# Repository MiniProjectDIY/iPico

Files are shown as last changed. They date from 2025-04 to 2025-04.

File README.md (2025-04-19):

# iPico
RP2350 based UF2 hardware security key

## Hardware

iPico use the same IO as official raspberry pi Pico2 board, just replaced physical push button with capacitive touch button on pcb and change usb connector from female to male.

## Firmware
Use  [pico-fido](https://github.com/polhenarejos/pico-fido/releases) firmware for pico 2 board will do.

## Enclosure

3d printed case using file from 3D folder,using M1.4* 2 heat inserts and M1.4*5 counter sink screws.





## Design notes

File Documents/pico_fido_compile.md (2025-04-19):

# install sdk
```
git clone -b master https://github.com/raspberrypi/pico-sdk.git
cd pico-sdk
 git submodule update --init  --recursive
```
# install toolchain
`sudo apt install cmake gcc-arm-none-eabi build-essential   `
# install pico-fido source
```
git clone https://github.com/polhenarejos/pico-fido.git -b development
cd pico-fido
git submodule update --init  --recursive
mkdir build
cd build
```
# export PICO_SDK_PATH
`export PICO_SDK_PATH=/home/lifetyper/Code/pico-sdk`
# build using yubikey 5 NFC pid
```
cmake .. -DPICO_BOARD=pico2  -DUSB_VID=0x1050 -DUSB_PID=0x0407 -DENABLE_EDDSA=1
make
```

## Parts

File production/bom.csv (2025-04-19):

Designator | Footprint | Quantity | Value | LCSC Part #
C1 | 0402 | 1 | C_0402_4.7uF_6.3V_X5R
C11, C12, C14, C15, C18, C19, C6, C7 | 0402 | 8 | C_0402_100nF_10V_X7R
C13, C16 | 0402 | 2 | C_0402_15pF_50V_C0G
C2, C5 | 0402 | 2 | C_0402_10uF_10V_X5R
C20, C21, C22, C8 | 0402 | 4 | C_0402_4.7uF_10V_X5R
C3 | 0402 | 1 | C_0402_1uF_10V_X5R
C4 | 0402 | 1 | C_0402_1pF_50V_C0G
D1, D2 | 0402 | 2 | TPESD0402G05V
D3 | 0402 | 1 | NCD0402B1
F1 | 0402 | 1 | BSMD0402L-020
H1, H2, H3, H4 | MountingHole-M1.4 | 4 | MountingHole_Pad
J1 | GT-USB-8016A | 1 | GT-USB-8016A
JP1 | SolderJumper-2_P1.3mm_Open_Pad1.0x1.5mm | 1 | Jumper_2_Open
L1 | LT_L0806 | 1 | AOTA-B201610S3R3-101-T
R1 | 0402 | 1 | R_0402_5.1K_5%
R10 | 0402 | 1 | R_0402_33_5%
R2, R3, R4 | 0402 | 3 | R_0402_27_5%
R5, R6 | 0402 | 2 | R_0402_1K_5%
R7 | 0402 | 1 | R_0402_470_5%
U1 | USON8-2x3mm-EP0.2x1.6mm | 1 | ZD25WQ32CEIGR
U2 | RP2350A_QFN-60_EP_7.75x7.75_Pitch0.4mm | 1 | RP2350A-QFN60
U4 | SOT-23-6 | 1 | TTP223_SOT23-6
U5 | SOT-23 | 1 | 662K
Y1 | Crystal_SMD_2520-4Pin_2.5x2.0mm | 1 | ABM8-272-T3

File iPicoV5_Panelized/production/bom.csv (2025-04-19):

Designator | Footprint | Quantity | Value | LCSC Part #
_2, |  | 2
C1_5, C1_4, C1_3, C1_2, C1, C2_5, C2_4, C2_3, C2_2, C2, C20_5, C20_4, C20_3, C20_2, C20, C21_5, C21_4, C21_3, C21_2, C21, C22_5, C22_4, C22_3, C22_2, C22, C5_5, C5_4, C5_3, C5_2, C5, C8_5, C8_4, C8_3, C8_2, C8 | 0402 | 35 | C_0402_4.7uF_10V_X5R
C11_5, C11_4, C11_3, C11_2, C11, C12_5, C12_4, C12_3, C12_2, C12, C14_5, C14_4, C14_3, C14_2, C14, C15_5, C15_4, C15_3, C15_2, C15, C18_5, C18_4, C18_3, C18_2, C18, C19_5, C19_4, C19_3, C19_2, C19, C6_5, C6_4, C6_3, C6_2, C6, C7_5, C7_4, C7_3, C7_2, C7 | 0402 | 40 | C_0402_100nF_10V_X7R
C13_5, C13_4, C13_3, C13_2, C13, C16_5, C16_4, C16_3, C16_2, C16 | 0402 | 10 | C_0402_15pF_50V_C0G
C3_5, C3_4, C3_3, C3_2, C3 | 0402 | 5 | C_0402_1uF_10V_X5R
C4_5, C4_4, C4_3, C4_2, C4 | 0402 | 5 | C_0402_1pF_50V_C0G
D1_5, D1_4, D1_3, D1_2, D1, D2_5, D2_4, D2_3, D2_2, D2 | 0402 | 10 | TPESD0402G05V
D3_5, D3_4, D3_3, D3_2, D3 | 0603 | 5 | NCD0603B1
F1_5, F1_4, F1_3, F1_2, F1 | 0402 | 5 | BSMD0402L-020
J1_5, J1_4, J1_3, J1_2, J1 | GT-USB-8016A | 5 | GT-USB-8016A
L1_5, L1_4, L1_3, L1_2, L1 | LT_L0806 | 5 | AOTA-B201610S3R3-101-T
R1_5, R1_4, R1_3, R1_2, R1 | 0402 | 5 | R_0402_5.1K_5%
R10_5, R10_4, R10_3, R10_2, R10 | 0402 | 5 | R_0402_33_5%
R2_5, R2_4, R2_3, R2_2, R2, R3_5, R3_4, R3_3, R3_2, R3, R4_5, R4_4, R4_3, R4_2, R4 | 0402 | 15 | R_0402_27_5%
R5_5, R5_4, R5_3, R5_2, R5, R6_5, R6_4, R6_3, R6_2, R6 | 0402 | 10 | R_0402_1K_5%
R7_5, R7_4, R7_3, R7_2, R7 | 0402 | 5 | R_0402_470_5%
U1_5, U1_4, U1_3, U1_2, U1 | USON8-2x3mm-EP0.2x1.6mm | 5 | ZD25WQ32CEIGR
U2_5, U2_4, U2_3, U2_2, U2 | RP2350A_QFN-60_EP_7.75x7.75_Pitch0.4mm | 5 | RP2350A-QFN60
U4_5, U4_4, U4_3, U4_2, U4 | SOT-23-6 | 5 | TTP223_SOT23-6
U5_5, U5_4, U5_3, U5_2, U5 | SOT-23 | 5 | 662K
Y1_5, Y1_4, Y1_3, Y1_2, Y1 | Crystal_SMD_2520-4Pin_2.5x2.0mm | 5 | ABM8-272-T3

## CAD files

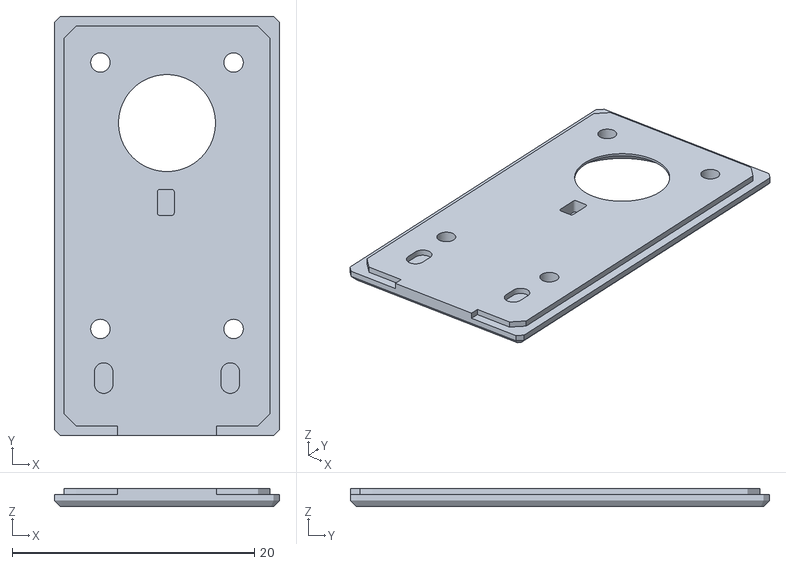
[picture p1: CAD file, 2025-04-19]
3D/iPicoV5_Enclosure-Lid.stl
18.6 x 34.6 x 1.50

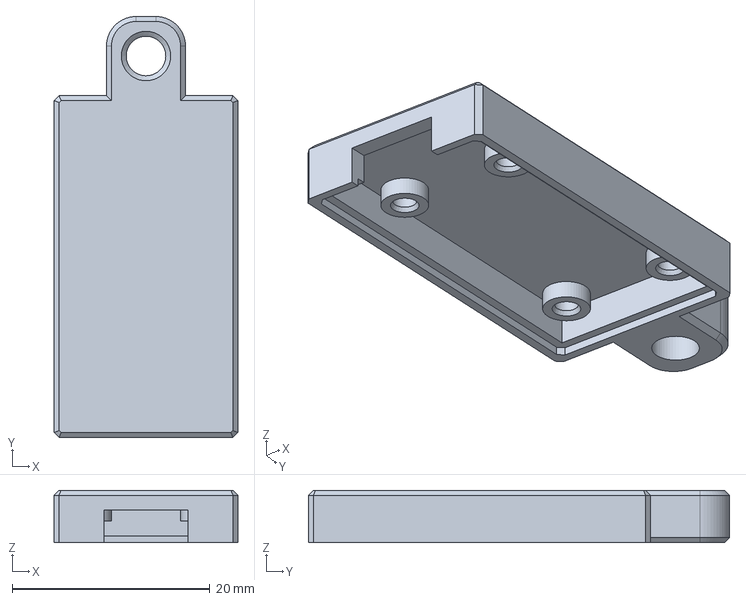
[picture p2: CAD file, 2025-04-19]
3D/iPicoV5_Enclosure.FCStd
18.6 x 42.6 x 5.30 mm

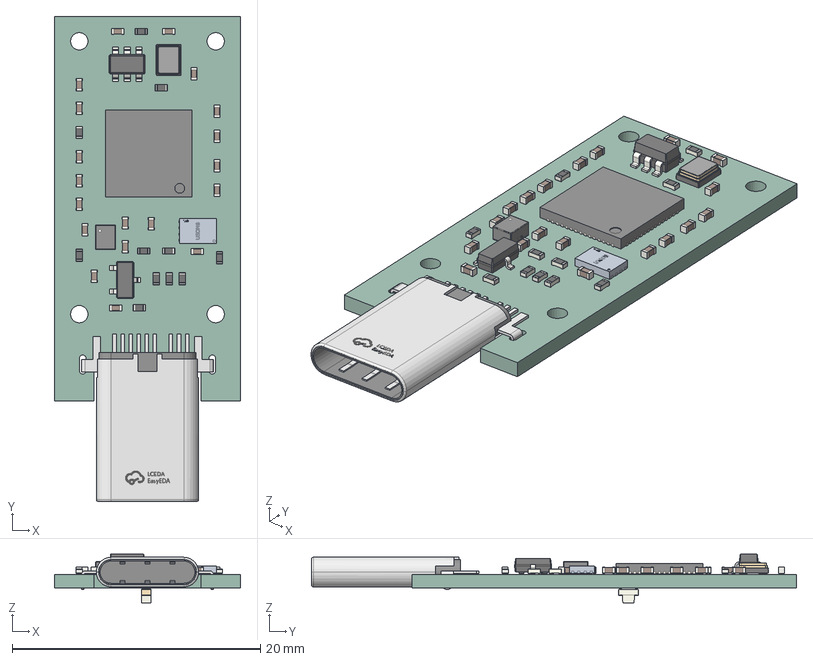
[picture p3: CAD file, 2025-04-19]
3D/iPico_V5.step
15.0 x 39.1 x 3.93 mm
R_0402_1005Metric x 10
C_0402_1005Metric x 19
Crystal_SMD_2520-4Pin_2.5x2.0mm
SOT-23
SOT-23-6
iPico_V5 1.27.1
IND-SMD_L2.0-W1.6_AOTA-B201610S3R3-101-T
Fuse_0402_1005Metric
RP2350A-QFN60
LED_0603_1608Metric
iPico_V5_PCB

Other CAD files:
2D/outline.FCStd
3D/iPicoV5_Enclosure-Bottom.stl
2D/outline.dxf

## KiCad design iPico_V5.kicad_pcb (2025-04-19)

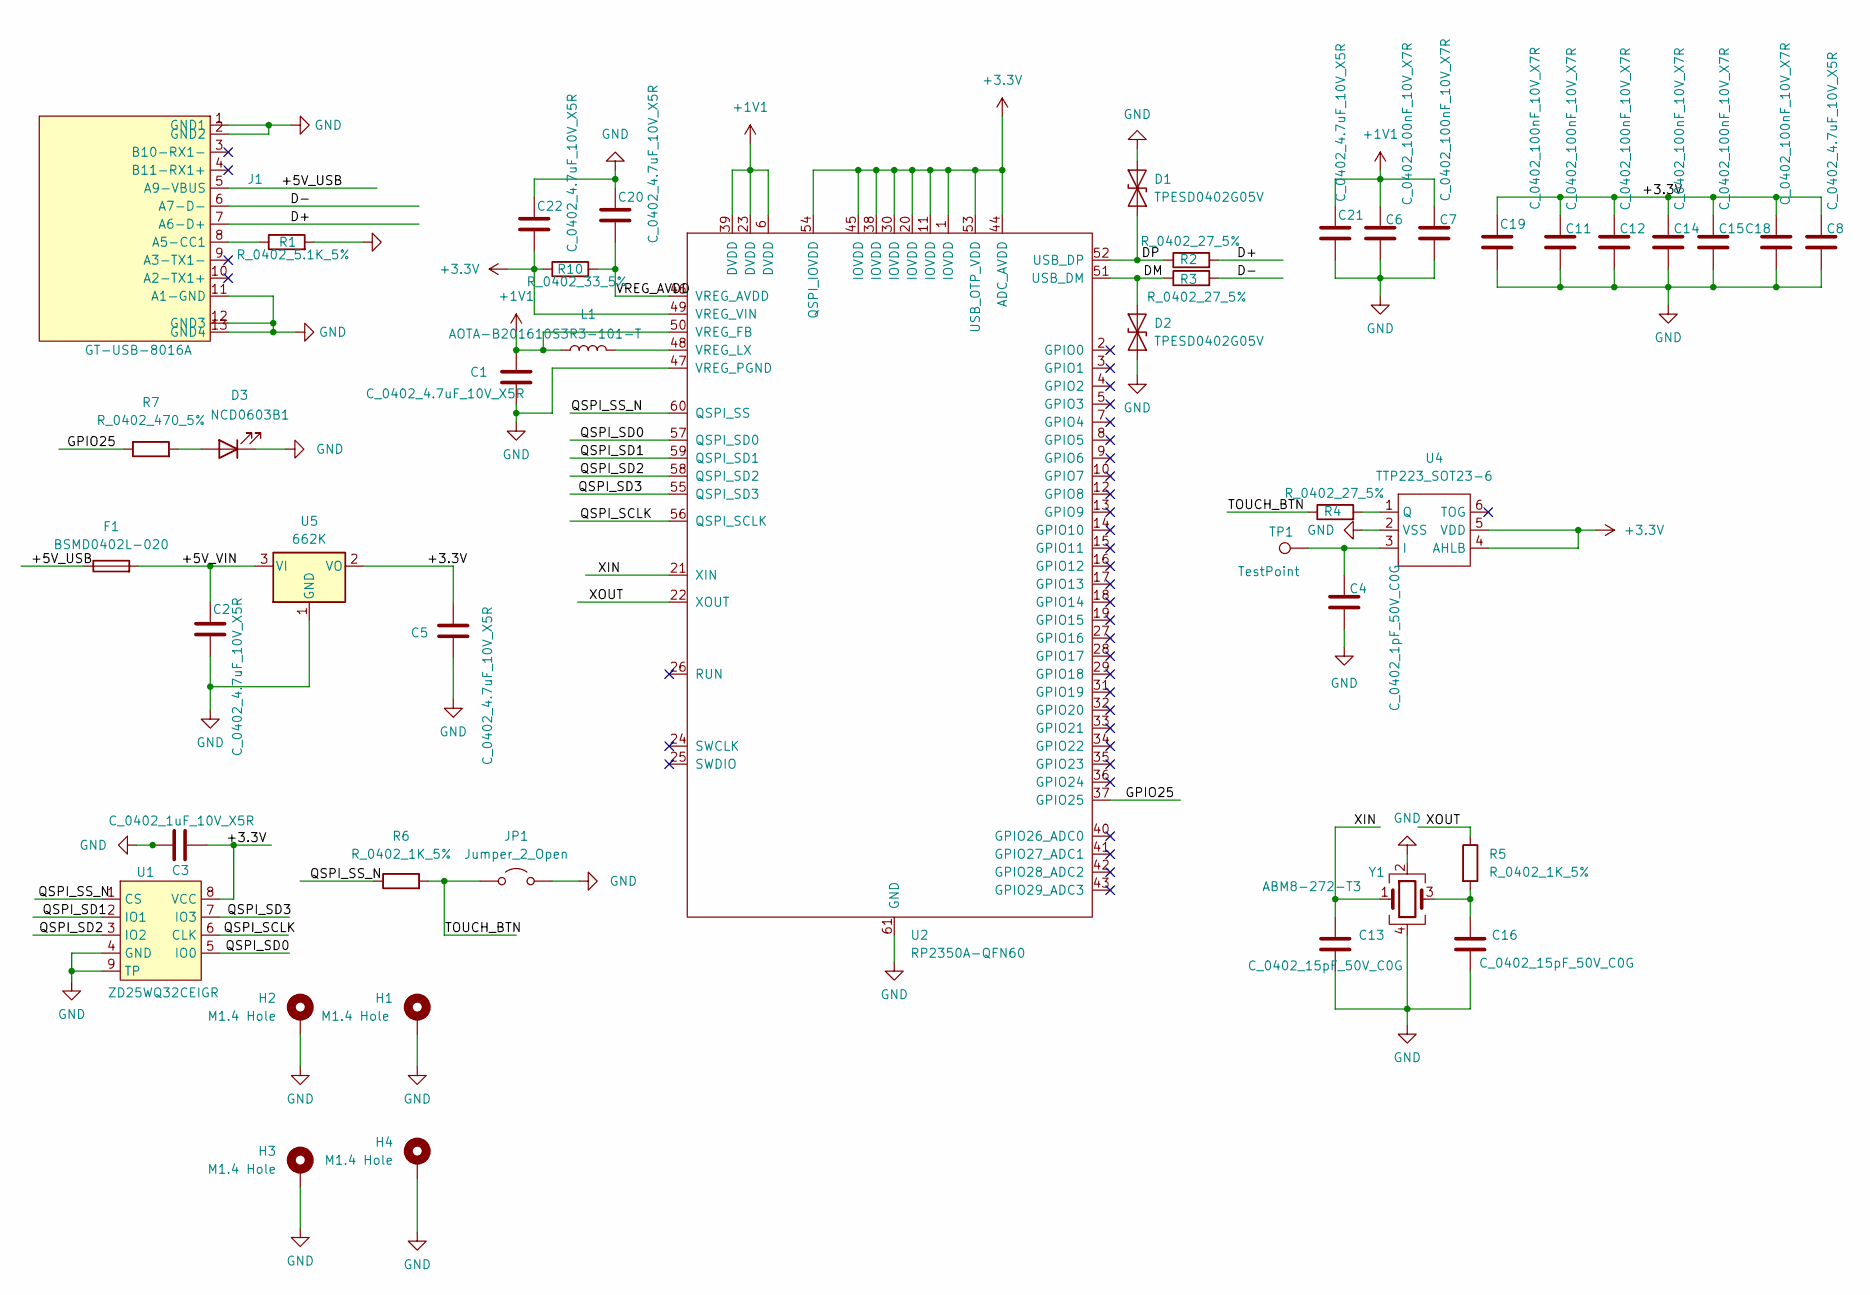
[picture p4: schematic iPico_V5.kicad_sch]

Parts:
C1, C2, C5, C8, C20, C21, C22: C_0402_4.7uF_10V_X5R; C_0402_1005Metric
C3: C_0402_1uF_10V_X5R; C_0402_1005Metric
C4: C_0402_1pF_50V_C0G; C_0402_1005Metric
C6, C7, C11, C12, C14, C15, C18, C19: C_0402_100nF_10V_X7R; C_0402_1005Metric
C13, C16: C_0402_15pF_50V_C0G; C_0402_1005Metric
D1, D2: TPESD0402G05V; R_0402_1005Metric
D3: NCD0603B1; LED_0603_1608Metric
F1: BSMD0402L-020; Fuse_0402_1005Metric
H1, H2, H3, H4: M1.4 Hole; MountingHole-M1.4
J1: GT-USB-8016A
JP1: Jumper_2_Open; SolderJumper-2_P1.3mm_Open_Pad1.0x1.5mm
L1: AOTA-B201610S3R3-101-T; LT_L0806
R1: R_0402_5.1K_5%; R_0402_1005Metric
R2, R3, R4: R_0402_27_5%; R_0402_1005Metric
R5, R6: R_0402_1K_5%; R_0402_1005Metric
R7: R_0402_470_5%; R_0402_1005Metric
R10: R_0402_33_5%; R_0402_1005Metric
TP1: TestPoint; TP_8MM
U1: ZD25WQ32CEIGR; USON8-2x3mm-EP0.2x1.6mm
U2: RP2350A-QFN60; RP2350A_QFN-60_EP_7.75x7.75_Pitch0.4mm
U4: TTP223_SOT23-6; SOT-23-6
U5: 662K; SOT-23
Y1: ABM8-272-T3; Crystal_SMD_2520-4Pin_2.5x2.0mm

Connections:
+1V1: C1.1, C6.1, C7.1, C21.2, L1.1, U2.6 (DVDD), U2.23 (DVDD), U2.39 (DVDD), U2.50 (VREG_FB)
+3.3V: C3.2, C5.1, C8.1, C11.1, C12.1, C14.1, C15.1, C18.1, C19.2, C22.1, R10.1, U1.8 (VCC), U2.1 (IOVDD), U2.11 (IOVDD), U2.20 (IOVDD), U2.30 (IOVDD), U2.38 (IOVDD), U2.44 (ADC_AVDD), U2.45 (IOVDD), U2.49 (VREG_VIN), U2.53 (USB_OTP_VDD), U2.54 (QSPI_IOVDD), U4.4 (AHLB), U4.5 (VDD), U5.2 (VO)
/+5V_USB: F1.1, J1.5 (A9-VBUS)
/+5V_VIN: C2.1, F1.2, U5.3 (VI)
/D+: J1.7 (A6-D+), R2.2
/D-: J1.6 (A7-D-), R3.2
/DM: D2.2 (A2), R3.1, U2.51 (USB_DM)
/DP: D1.1 (A1), R2.1, U2.52 (USB_DP)
/GPIO25: R7.1, U2.37 (GPIO25)
/QSPI_SCLK: U1.6 (CLK), U2.56 (QSPI_SCLK)
/QSPI_SD0: U1.5 (IO0), U2.57 (QSPI_SD0)
/QSPI_SD1: U1.2 (IO1), U2.59 (QSPI_SD1)
/QSPI_SD2: U1.3 (IO2), U2.58 (QSPI_SD2)
/QSPI_SD3: U1.7 (IO3), U2.55 (QSPI_SD3)
/QSPI_SS_N: R6.1, U1.1 (CS), U2.60 (QSPI_SS)
/TOUCH_BTN: JP1.1 (A), R4.1, R6.2
/VREG_AVDD: C20.1, R10.2, U2.46 (VREG_AVDD)
/XIN: C13.1, U2.21 (XIN), Y1.1
/XOUT: R5.1, U2.22 (XOUT)
GND: C1.2, C2.2, C3.1, C4.2, C5.2, C6.2, C7.2, C8.2, C11.2, C12.2, C13.2, C14.2, C15.2, C16.2, C18.2, C19.1, C20.2, C21.1, C22.2, D1.2 (A2), D2.1 (A1), D3.1 (K), H1.1, H2.1, H3.1, H4.1, J1.1 (GND1), J1.2 (GND2), J1.11 (A1-GND), J1.12 (GND3), J1.13 (GND4), JP1.2 (B), R1.2, U1.4 (GND), U1.9 (TP), U2.47 (VREG_PGND), U2.61 (GND), U4.2 (VSS), U5.1 (GND), Y1.2, Y1.4
unnamed: C16.1, R5.2, Y1.3
unnamed: D3.2 (A), R7.2
unnamed: J1.8 (A5-CC1), R1.1
unnamed: L1.2, U2.48 (VREG_LX)
unnamed: C4.1, TP1.1, U4.3 (I)
unnamed: R4.2, U4.1 (Q)

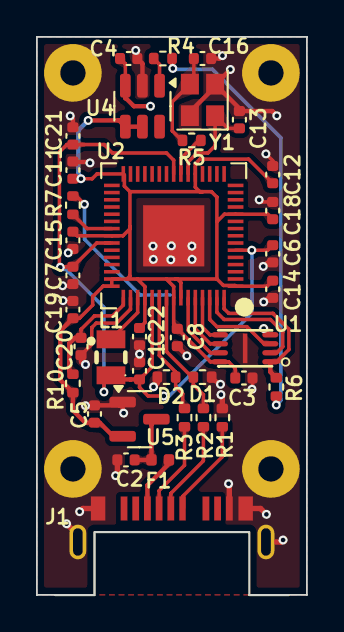
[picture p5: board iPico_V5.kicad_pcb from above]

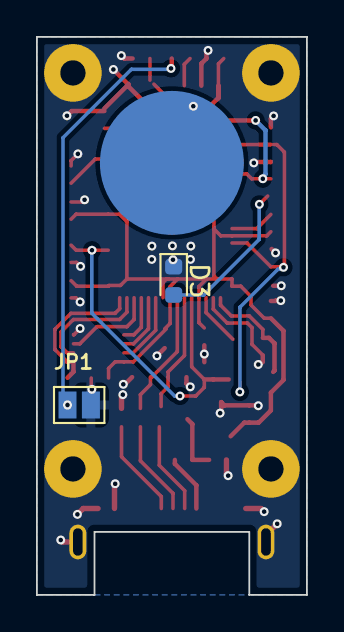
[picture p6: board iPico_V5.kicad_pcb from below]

Board: 2 copper layers, 15.0 x 31.0 mm, 44 parts (3 on the bottom side), 26 nets.

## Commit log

2025-04-19 V5 Initial
    [bom.csv, designators.csv, iPicoV5_Enclosure-Bottom.stl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]
2025-04-19 add pico fido compile documents
    [iPicoV5_Enclosure-Bottom.stl, iPicoV5_Enclosure-Lid.stl, iPicoV5_Enclosure.FCStd]
